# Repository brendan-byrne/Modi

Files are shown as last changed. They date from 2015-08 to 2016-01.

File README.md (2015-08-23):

#Modi Controller Series#
Xiwi Electronics - [http://xiwielectronics.com/](http://xiwielectronics.com/)  
Brendan Byrne - [http://brendanbyrne.info](http://brendanbyrne.info)  
Assembly Instructions - [http://brendanbyrne.info/Hybri-Assembly-Instructions](http://brendanbyrne.info/Hybri-Assembly-Instructions)



**DESCRIPTION**  
Modi is a expandable controller bank system designed for AVR microcontroller platforms like Arduino and Teensy. There are four distinct module types available, each consisting of either 8 or 16 individually readable analog or digital controllers. Modi boards can be stacked to support up to 64 inputs making them ideal for MIDI/OSC projects.

**INSTALLATION**  
After downloading, move the *Modi* folder to your *Arduino Libraries* folder. Restart the Arduino IDE if already running, then open *File->Examples->Modi>allReadings* sketch.

**CLASSES AND METHODS**  
*CONSTRUCTOR*  
Modi Matrix(byte pcbA, byte pcbB, byte pcbC, byte toggleSmoothing)

- Set the arguments pcbA, pcbB, and pcbC to the pins that the Modi A, B, and C PCB pins are connected to. These can be any digital output pins.
- The toggleSmoothing argument allows you to turn a simple smoothing function on and off.
	- 0 = no smoothing
	- 1 = smooth by [Paul Badger 2007](http://tiny.cc/0db2rx) 
		- You have the option of changing the amount of smoothing. *Matrix.smoothingAmount* stores this value. .0001 indicates minimum smoothing while  .999 results in maximum smoothing. The default value is .5
 
*ATTACHING PINS*  
void Matrix.attach(byte pin, String type)

- Call this method in the setup() portion of your sketch.
- Start with the top most row. The library uses this to reference its position automatically.
- The pin argument indicates the pin the row is connected to.
- The second argument indicates the kind of row. The Modi library recognizes the following three strings: "pot", "button", and "slide".
- The numbers for signal paths on the PCB are entirely arbitary and are intended to be used to plan *electronically*.
    
*NEW READINGS*     
void Matrix.refresh()

- Call this function at the beginning of each loop to refresh readings.
  
*GET READINGS*    
int Matrix.getReading(byte row, byte column)

- Call this function to retrieve the readings from the Modi grid.
- (0, 0) is the top-left most controller 
- The Grid object supports a matrix of up to (7, 7)
- Pins marked as "buttons" will return a 0 or 1
- Pins marked as "pot" or "slide" will return values between 0 and 1023

**CONSTANTS AND ATTRIBUTES**  
*muxChannels*  
The number of channels the 4051 multiplexer supports. This constant's value is 8.

*Matrix.smoothAmount*  
When toggleSmoothing is activated this attribute determines the amount of smoothing applied to readings. .001 indicates minimum smoothing while .999 results in maximum smoothing. The default value is .5

*Matrix.numMux*  
numMux is equal to the number of times attach() is called in setup which should also be equal to the total number of multiplexers in your Modi system.

*Matrix.analogType[]*  
An array that stores whether analogRead() or digitalRead() is to be used when collecting readings. This attribute comes in handy when utilizing different commands with different controller types. In the case of  the midiOut example sketch contained within this library, the attribute is used to send some readings as Note On/Off messages and others as CC messages. 0 = digital and 1 = analog

**OPEN SOURCE**  
Modi is an Open-Source Hardware 1.0 Project

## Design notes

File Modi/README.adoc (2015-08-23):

= Modi Library for Arduino + Teensy =

This library facilitates communication between the Modi PCB and Arduino/Teensy microcontrollers. 

For more information about this library please visit us at
https://github.com/brendan-byrne/Modi

== License ==

Copyright (c) Xiwi Electronics. All right reserved.

This library is free software; you can redistribute it and/or
modify it under the terms of the GNU Lesser General Public
License as published by the Free Software Foundation; either
version 2.1 of the License, or (at your option) any later version.

This library is distributed in the hope that it will be useful,
but WITHOUT ANY WARRANTY; without even the implied warranty of
MERCHANTABILITY or FITNESS FOR A PARTICULAR PURPOSE. See the GNU
Lesser General Public License for more details.

You should have received a copy of the GNU Lesser General Public
License along with this library; if not, write to the Free Software
Foundation, Inc., 51 Franklin St, Fifth Floor, Boston, MA 02110-1301 USA

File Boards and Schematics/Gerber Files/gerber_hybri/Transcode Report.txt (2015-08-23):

   ---- Transcoding 'C:\Users\nopanda\Desktop\Projects\Modi\Gerber Files\gerber_hybri\modularHybri.GTL' ----   Thu Sep 04 17:01:52 2014

D16   --> D100
D17   --> D101
-----------------------------------------------------------------

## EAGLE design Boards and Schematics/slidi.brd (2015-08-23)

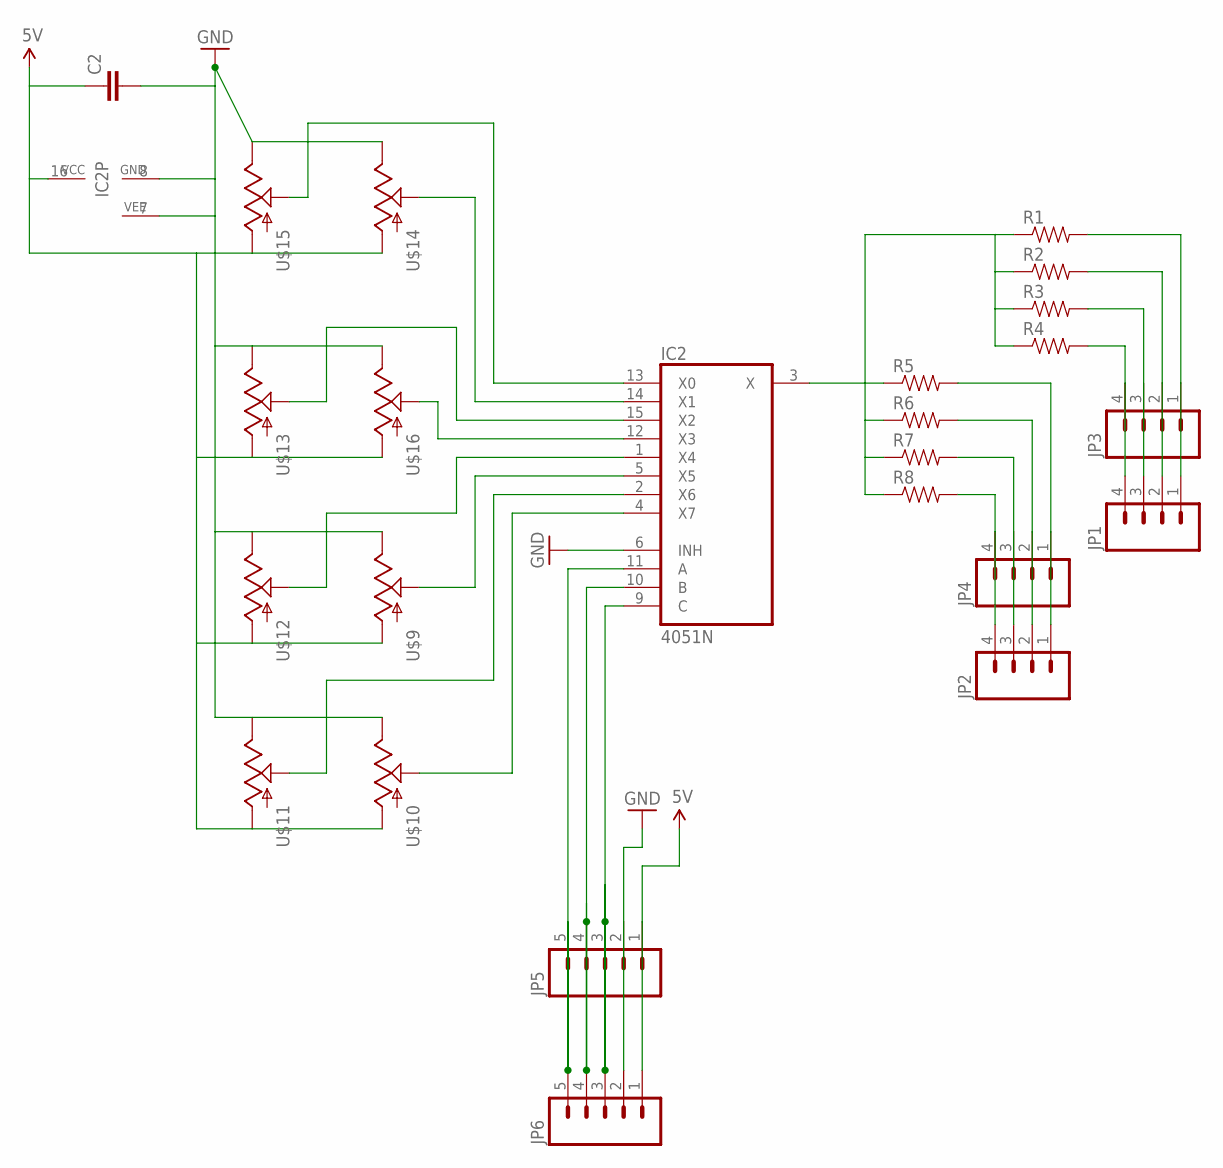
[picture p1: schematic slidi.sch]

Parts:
C2: CAPPTH; CAP-PTH-SMALL
IC2: 4051N; DIL16
JP1, JP2, JP3, JP4: M04PTH; 1X04
JP5, JP6: M05PTH; 1X05
R1, R2, R3, R4, R5, R6, R7, R8: RESISTORAXIAL-0.3; AXIAL-0.3
U$9, U$10, U$11, U$12, U$13, U$14, U$15, U$16: SLIDEPOT

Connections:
5V: C2.1, IC2.16 (VCC), JP5.1, JP6.1, U$9.GND (A), U$10.GND (A), U$11.GND (A), U$12.GND (A), U$13.GND (A), U$14.GND (A), U$15.GND (A), U$16.GND (A)
GND: C2.2, IC2.6 (INH), IC2.7 (VEE), IC2.8 (GND), JP5.2, JP6.2, U$9.5V (E), U$10.5V (E), U$11.5V (E), U$12.5V (E), U$13.5V (E), U$14.5V (E), U$15.5V (E), U$16.5V (E)
unnamed: IC2.14 (X1), U$14.WIPER (S)
unnamed: IC2.13 (X0), U$15.WIPER (S)
unnamed: IC2.15 (X2), U$13.WIPER (S)
unnamed: IC2.12 (X3), U$16.WIPER (S)
unnamed: IC2.1 (X4), U$12.WIPER (S)
unnamed: IC2.5 (X5), U$9.WIPER (S)
unnamed: IC2.2 (X6), U$11.WIPER (S)
unnamed: IC2.4 (X7), U$10.WIPER (S)
unnamed: IC2.3 (X), R1.P$1 (1), R2.P$1 (1), R3.P$1 (1), R4.P$1 (1), R5.P$1 (1), R6.P$1 (1), R7.P$1 (1), R8.P$1 (1)
unnamed: IC2.10 (B), JP5.4, JP6.4
unnamed: IC2.11 (A), JP5.5, JP6.5
unnamed: IC2.9 (C), JP5.3, JP6.3
unnamed: JP1.4, JP3.4, R4.P$2 (2)
unnamed: JP1.3, JP3.3, R3.P$2 (2)
unnamed: JP1.2, JP3.2, R2.P$2 (2)
unnamed: JP1.1, JP3.1, R1.P$2 (2)
unnamed: JP2.4, JP4.4, R8.P$2 (2)
unnamed: JP2.3, JP4.3, R7.P$2 (2)
unnamed: JP2.2, JP4.2, R6.P$2 (2)
unnamed: JP2.1, JP4.1, R5.P$2 (2)

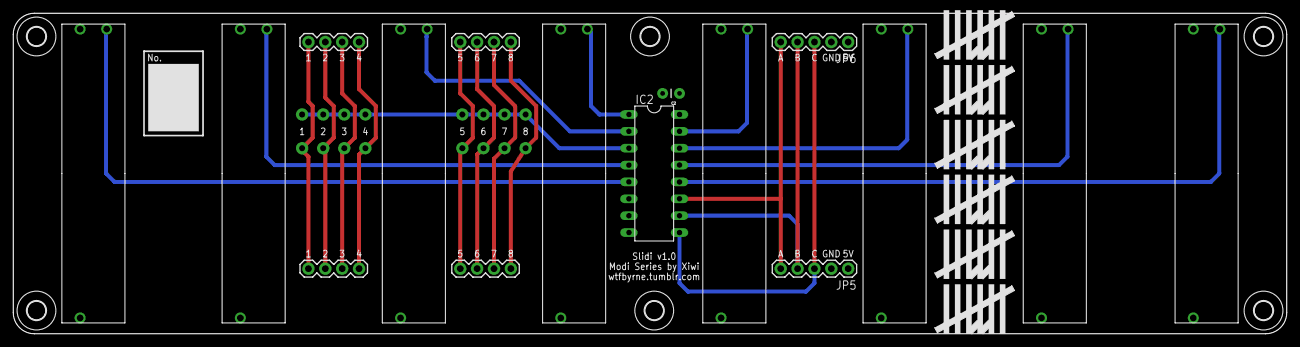
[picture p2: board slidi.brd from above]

Board: 2 copper layers, 191.8 x 48.3 mm, 36 parts (0 on the bottom side), 22 nets.

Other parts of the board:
U$17, U$18, U$19, U$20, U$21, U$22: 2,8
U$23, U$24, U$25, U$26, U$27, U$28: XIWI

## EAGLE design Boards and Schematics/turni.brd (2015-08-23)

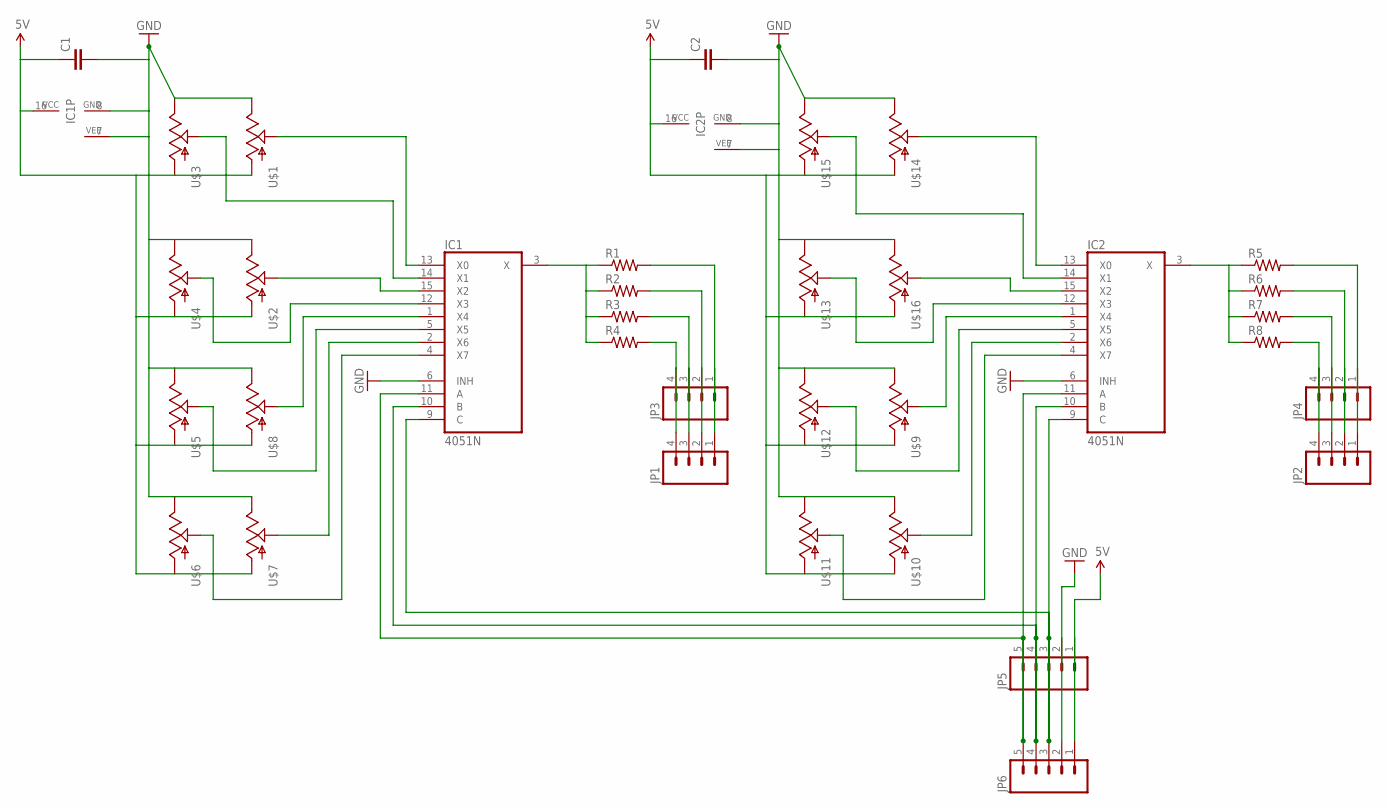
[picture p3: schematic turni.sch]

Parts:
C1, C2: CAPPTH; CAP-PTH-SMALL
IC1, IC2: 4051N; DIL16
JP1, JP2, JP3, JP4: M04PTH; 1X04
JP5, JP6: M05PTH; 1X05
R1, R2, R3, R4, R5, R6, R7, R8: RESISTORAXIAL-0.3; AXIAL-0.3
U$1, U$2, U$3, U$4, U$5, U$6, U$7, U$8, U$9, U$10, U$11, U$12, U$13, U$14, U$15, U$16: POT; ALPS_POT

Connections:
5V: C1.1, C2.1, IC1.16 (VCC), IC2.16 (VCC), JP5.1, JP6.1, U$1.P$3 (A), U$2.P$3 (A), U$3.P$3 (A), U$4.P$3 (A), U$5.P$3 (A), U$6.P$3 (A), U$7.P$3 (A), U$8.P$3 (A), U$9.P$3 (A), U$10.P$3 (A), U$11.P$3 (A), U$12.P$3 (A), U$13.P$3 (A), U$14.P$3 (A), U$15.P$3 (A), U$16.P$3 (A)
GND: C1.2, C2.2, IC1.6 (INH), IC1.7 (VEE), IC1.8 (GND), IC2.6 (INH), IC2.7 (VEE), IC2.8 (GND), JP5.2, JP6.2, U$1.P$1 (E), U$2.P$1 (E), U$3.P$1 (E), U$4.P$1 (E), U$5.P$1 (E), U$6.P$1 (E), U$7.P$1 (E), U$8.P$1 (E), U$9.P$1 (E), U$10.P$1 (E), U$11.P$1 (E), U$12.P$1 (E), U$13.P$1 (E), U$14.P$1 (E), U$15.P$1 (E), U$16.P$1 (E)
unnamed: IC1.13 (X0), U$1.P$2 (S)
unnamed: IC1.14 (X1), U$3.P$2 (S)
unnamed: IC1.15 (X2), U$2.P$2 (S)
unnamed: IC1.12 (X3), U$4.P$2 (S)
unnamed: IC1.1 (X4), U$8.P$2 (S)
unnamed: IC1.5 (X5), U$5.P$2 (S)
unnamed: IC1.2 (X6), U$7.P$2 (S)
unnamed: IC1.4 (X7), U$6.P$2 (S)
unnamed: IC2.13 (X0), U$14.P$2 (S)
unnamed: IC2.14 (X1), U$15.P$2 (S)
unnamed: IC2.15 (X2), U$16.P$2 (S)
unnamed: IC2.12 (X3), U$13.P$2 (S)
unnamed: IC2.1 (X4), U$9.P$2 (S)
unnamed: IC2.5 (X5), U$12.P$2 (S)
unnamed: IC2.2 (X6), U$10.P$2 (S)
unnamed: IC2.4 (X7), U$11.P$2 (S)
unnamed: IC1.3 (X), R1.P$1 (1), R2.P$1 (1), R3.P$1 (1), R4.P$1 (1)
unnamed: IC1.10 (B), IC2.10 (B), JP5.4, JP6.4
unnamed: IC1.11 (A), IC2.11 (A), JP5.5, JP6.5
unnamed: IC1.9 (C), IC2.9 (C), JP5.3, JP6.3
unnamed: JP1.4, JP3.4, R4.P$2 (2)
unnamed: JP1.3, JP3.3, R3.P$2 (2)
unnamed: JP1.2, JP3.2, R2.P$2 (2)
unnamed: JP1.1, JP3.1, R1.P$2 (2)
unnamed: IC2.3 (X), R5.P$1 (1), R6.P$1 (1), R7.P$1 (1), R8.P$1 (1)
unnamed: JP2.4, JP4.4, R8.P$2 (2)
unnamed: JP2.3, JP4.3, R7.P$2 (2)
unnamed: JP2.2, JP4.2, R6.P$2 (2)
unnamed: JP2.1, JP4.1, R5.P$2 (2)

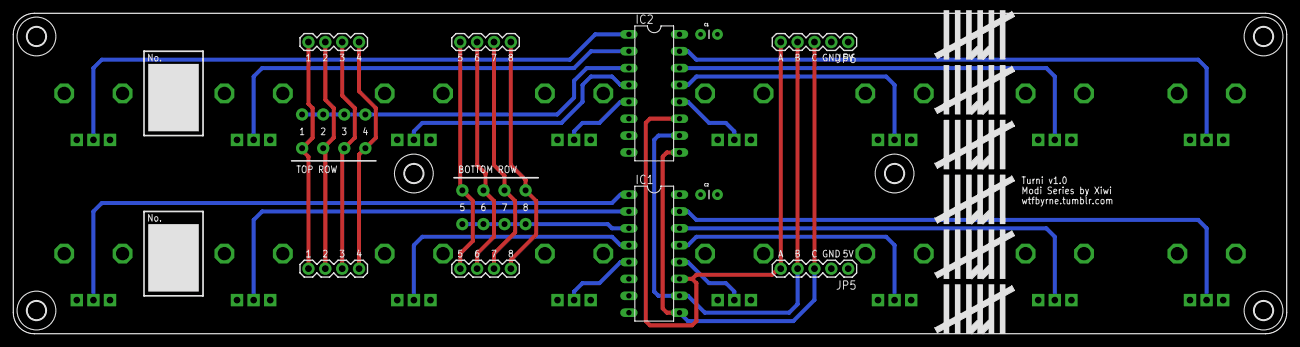
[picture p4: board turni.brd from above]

Board: 2 copper layers, 191.8 x 48.3 mm, 46 parts (0 on the bottom side), 31 nets.

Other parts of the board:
U$17, U$18, U$19, U$20, U$21, U$22: 2,8
U$23, U$24, U$25, U$26, U$27, U$28: XIWI

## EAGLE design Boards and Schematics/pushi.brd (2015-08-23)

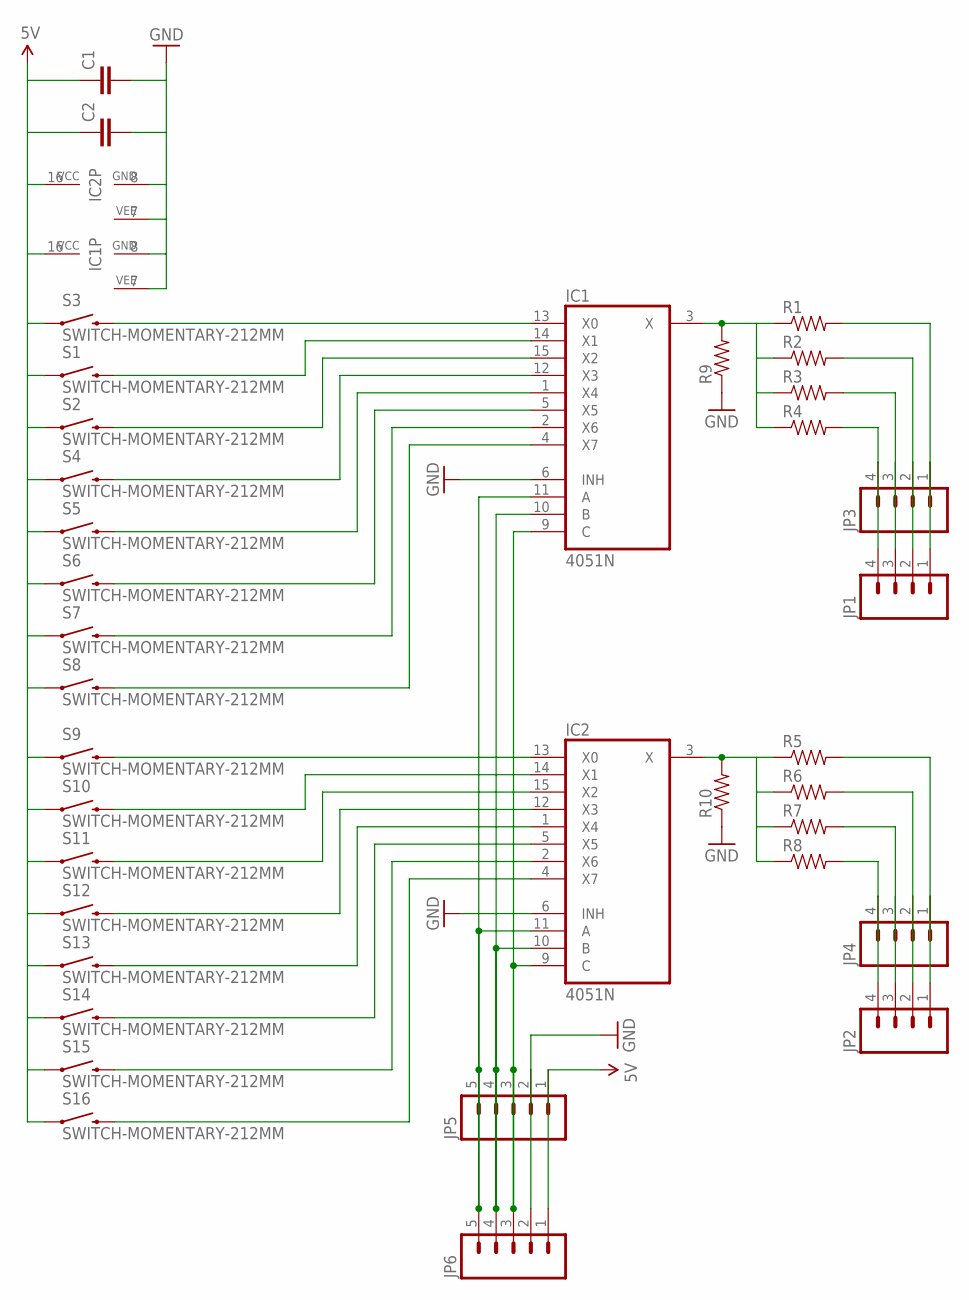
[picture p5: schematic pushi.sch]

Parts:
C1, C2: CAPPTH; CAP-PTH-SMALL
IC1, IC2: 4051N; DIL16
JP1, JP2, JP3, JP4: M04PTH; 1X04
JP5, JP6: M05PTH; 1X05
R1, R2, R3, R4, R5, R6, R7, R8, R9, R10: RESISTORAXIAL-0.3; AXIAL-0.3
S1, S2, S3, S4, S5, S6, S7, S8, S9, S10, S11, S12, S13, S14, S15, S16: SWITCH-MOMENTARY-212MM; TACTILE-PTH-12MM

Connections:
5V: C1.1, C2.1, IC1.16 (VCC), IC2.16 (VCC), JP5.1, JP6.1, S1.1, S2.1, S3.1, S4.1, S5.1, S6.1, S7.1, S8.1, S9.1, S10.1, S11.1, S12.1, S13.1, S14.1, S15.1, S16.1
GND: C1.2, C2.2, IC1.6 (INH), IC1.7 (VEE), IC1.8 (GND), IC2.6 (INH), IC2.7 (VEE), IC2.8 (GND), JP5.2, JP6.2, R9.P$1 (1), R10.P$1 (1)
unnamed: IC1.15 (X2), S2.3 (2)
unnamed: IC1.14 (X1), S1.3 (2)
unnamed: IC1.12 (X3), S4.3 (2)
unnamed: IC1.1 (X4), S5.3 (2)
unnamed: IC1.5 (X5), S6.3 (2)
unnamed: IC1.2 (X6), S7.3 (2)
unnamed: IC1.4 (X7), S8.3 (2)
unnamed: IC2.13 (X0), S9.3 (2)
unnamed: IC2.14 (X1), S10.3 (2)
unnamed: IC2.15 (X2), S11.3 (2)
unnamed: IC2.12 (X3), S12.3 (2)
unnamed: IC2.1 (X4), S13.3 (2)
unnamed: IC2.5 (X5), S14.3 (2)
unnamed: IC2.2 (X6), S15.3 (2)
unnamed: IC2.4 (X7), S16.3 (2)
unnamed: IC1.3 (X), R1.P$1 (1), R2.P$1 (1), R3.P$1 (1), R4.P$1 (1), R9.P$2 (2)
unnamed: IC1.10 (B), IC2.10 (B), JP5.4, JP6.4
unnamed: IC1.11 (A), IC2.11 (A), JP5.5, JP6.5
unnamed: IC1.9 (C), IC2.9 (C), JP5.3, JP6.3
unnamed: JP1.4, JP3.4, R4.P$2 (2)
unnamed: JP1.3, JP3.3, R3.P$2 (2)
unnamed: JP1.2, JP3.2, R2.P$2 (2)
unnamed: JP1.1, JP3.1, R1.P$2 (2)
unnamed: IC2.3 (X), R5.P$1 (1), R6.P$1 (1), R7.P$1 (1), R8.P$1 (1), R10.P$2 (2)
unnamed: JP2.4, JP4.4, R8.P$2 (2)
unnamed: JP2.3, JP4.3, R7.P$2 (2)
unnamed: JP2.2, JP4.2, R6.P$2 (2)
unnamed: JP2.1, JP4.1, R5.P$2 (2)
unnamed: IC1.13 (X0), S3.3 (2)

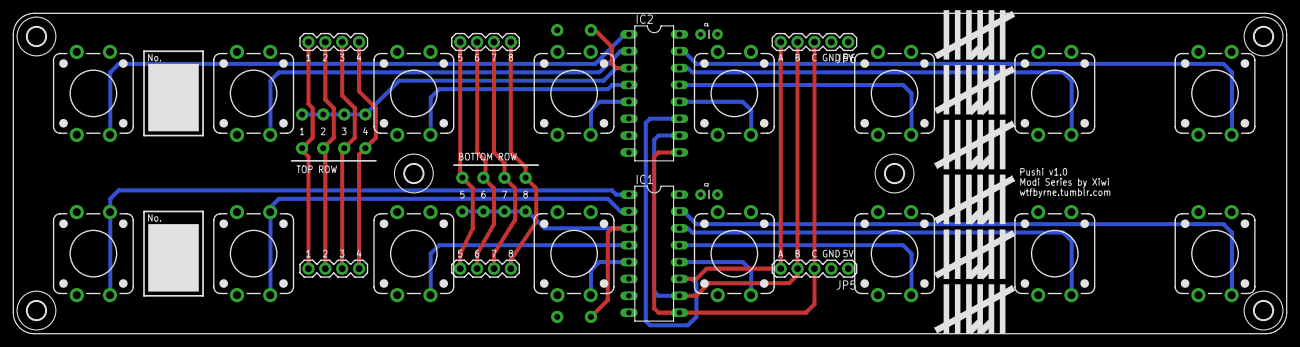
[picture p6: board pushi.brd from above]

Board: 2 copper layers, 191.8 x 48.3 mm, 48 parts (0 on the bottom side), 31 nets.

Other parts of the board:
U$17, U$18, U$19, U$20, U$21, U$22: 2,8
U$23, U$24, U$25, U$26, U$27, U$28: XIWI

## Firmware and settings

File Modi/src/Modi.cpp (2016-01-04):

#include "Arduino.h"
#include "Modi.h"

Modi::Modi(byte _selPinA, byte _selPinB, byte _selPinC, byte _smoothSel) {
  numMux = 0;                                           // This number increases by 1 with each attach() method used        
  smoothAmount = .5;                                    // Default amount of smoothing
  smoothSel = _smoothSel;                               // Toggles smoothing
  if (smoothSel > 1 || smoothSel < 0) {                 // Set smoothSel to 0 if improper input received
    smoothSel = 0;
  }
  
  selPins[0] = _selPinA;                                // Assign selection pins to variables
  selPins[1] = _selPinB;
  selPins[2] = _selPinC; 
  
  for (int i=0; i<sizeof(selPins); i++) {               // Each selPins[] designated as OUTPUT
    pinMode(selPins[i], OUTPUT); 
  }
}

void Modi::attach(byte _pin, String _anaType) {
  if (_anaType == "slide") slideType[numMux] = 1;       // Stores the type of controllers to be read
  else slideType[numMux] = 0;                           // 1 = Slidi     0 = Not Slidi
  
  if (_anaType == "button") analogType[numMux] = 0;     // Stores whether controllers should be read using analog or digital read
  else analogType[numMux] = 1;                          // 1 = Analog    0 = Digital
 
  inputPins[numMux] = _pin;                              // Put assigned input pin into an array
  pinMode(inputPins[numMux], INPUT);                     // The new input pin is designated as an INPUT
  numMux++;                                              // Advance one step in array for next usage of attach() method
}

void Modi::refresh() {
  for (int x=0; x<muxChannels; x++) {                    // Stepping through the channels allows for changing selPins[] less often
    for (int y=0; y<numMux; y++) {                       // numMux taken from how many times attach method was used
      int rawVal;                                        // Local variable to store value of incoming reading
      if (analogType[y]) {                               // Are the readings from the multiplexer push button signals?
        rawVal = analogRead(inputPins[y]);               // Take the reading
        if (smoothSel) {                                 // Is smoothing enabled?        
         // Check to see whether the incoming signal is from a Slidi module to determine which organize array to use
         if (slideType[y]) finalVals[y][muxOrganizeSlidi[x]] = smooth(rawVal, smoothAmount, finalVals[y][muxOrganizeSlidi[x]]);
         else finalVals[y][muxOrganize[x]] = smooth(rawVal, smoothAmount, finalVals[y][muxOrganize[x]]);
        } 
        else {          
         // Check to see whether the incoming signal is from a Slidi module to determine which organize array to use
         if (slideType[y]) finalVals[y][muxOrganizeSlidi[x]] = rawVal;
         else finalVals[y][muxOrganize[x]] = rawVal;
        }
      }      
      else {                                             // Are the readings from the multiplexer push button signals?
        rawVal = digitalRead(inputPins[y]);              // Digital read the buttons
        finalVals[y][muxOrganize[x]] = rawVal;           // Assign the reading to the finalVals[][] array
      }
    }
    digitalWrite(selPins[changePins[x]], changeVals[x]); // Change the selection pins based on the two Gray Code arrays
  }
}

int Modi::getReading(byte _mux, byte _channel) {
  return finalVals[_mux][_channel];                      // Return a value from the finalVals[][] array
}

// smooth   v0.2 by Paul Badger 2007 - http://playground.arduino.cc/Main/Smooth
int Modi::smooth(int data, float filterVal, float smoothedVal) {
  if (filterVal > 1) filterVal = .99;
  else if (filterVal <= 0) filterVal = 0;
  smoothedVal = (data * (1 - filterVal)) + (smoothedVal  *  filterVal);
  return (int)smoothedVal;
}

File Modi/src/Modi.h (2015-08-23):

#ifndef Modi_h
#define Modi_h
#include "Arduino.h"

    /* --- NOTES ON CONSTANTS ------------------------------------------------------   
    changePin[] and changeVal[] 
    To increase the speed that Modi boards operate I used the following two arrays
    to facilitate a reading processs that uses as few digitalWrite() commands as 
    possible. This is accomplished by using Gray Code in which the state of only
    one pin is changed each loop. changePin[] contains the pin to be changed and 
    changeVal[] designates the state to change that pin to. 
    
    muxOrganize[] and muxOrganizeSlidi[] 
    The Gray code and the traces of the PCB causes the readings of the 4051 multi-
    plexers to be read out of order. These variables arrange the readings to fit
    and be read nicely from another array. If I had made perfect circuit boards these 
    variables would not have been necessary. 
    ----------------------------------------------------------------------------   */

const byte muxChannels = 8;                                     // The 4051 multiplexer has 8 channels
const byte changePins[] = {0, 1, 0, 2, 0, 1, 0, 2};
const boolean changeVals[] = {1, 1, 0, 1, 1, 0, 0, 0};
const byte muxOrganize[] = {5, 6, 4, 7, 1, 2, 3, 0};
const byte muxOrganizeSlidi[] = {6, 5, 7, 4, 2, 1, 0, 3};

class Modi {
  public:
    Modi(byte _selPinA, byte _selPinB, byte _selPinC, byte _smoothSel);
   
    byte numMux;                // This number starts at 0 and increases by 1 with each .attach method   
    float smoothAmount;         // Sets the amount of smoothing applied to signal
    boolean smoothSel;          // Determines whether to smooth incoming signals or not
    byte inputPins[8];          // Pins connected to the analog output of each 4051
    byte selPins[3];            // Connected to digital outputs of microcontroller. Determines channel selection
    boolean slideType[8];       // Holds values that determine which organize array to apply to incoming signals
    boolean analogType[8];      // Holds values that determine whether analogRead() or digitalRead() is used
    int finalVals[8][8];
  
    void attach(byte _pin, String _digiAna);                   // Associate microcontroller pin with a Modi multiplexer
    void refresh();                                            // Capture readings from all controllers
    int getReading(byte _mux, byte _channel);                  // Access a reading from finalVals[]
    int smooth(int data, float filterVal, float smoothedVal);  // Method for smoothing incoming readings
  private:
};

#endif

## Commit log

2015-08-23 Big Update
    [hybri.brd, hybri.sch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]
2016-01-04 Fixed digitalWrite call so the correct pins get selected
    [Modi.cpp]

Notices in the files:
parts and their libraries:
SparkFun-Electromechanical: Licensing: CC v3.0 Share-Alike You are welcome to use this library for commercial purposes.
